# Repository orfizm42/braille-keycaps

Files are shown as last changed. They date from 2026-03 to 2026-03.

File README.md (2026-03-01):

# braille-mx-keycaps

MX互換メカニカルキーボード向け、点字付き3Dプリントキーキャップ

---

## 概要

Cherry MX互換スイッチに対応した点字付きキーキャップのSTEPデータです。メカニカルキーボード愛好家・Makerコミュニティ・研究・教育目的での利用を想定しています。

STEPデータはGitHubで無料公開しています。
boothでも配布しています。
https://orfizm.booth.pm/items/8044609

---

## 特徴

- **62キーフルセット** — アルファベット・数字・ファンクション・修飾・ナビゲーションキーに対応
- **JIS T 0921 / UNESCO準拠の点字ドット** — 直径1.5mm・突出高さ0.5mm・セル間隔2.5mm
- **特殊キー識別リブ** — ファンクション・修飾キーなどの上面左端に縦リブ（高さ0.7mm・幅1.5mm）を配置。点字と混同しない形状で通常キーと触覚的に即座に区別できる設計。
- **OPKベース** — Matt3o氏のOPK（Open Programmatic Keycap、Apache 2.0）をベースに改変

---

## 点字パターンについての注意

特殊キー（Ctrl・Alt・Escなど）の点字パターンは、各キー名称の頭文字に対応するUEB（統一英語点字）Grade 1パターンを割り当てた**独自定義**です。国際標準規格による特殊キーの点字表記は存在しないため、実用目的での使用前に点字の専門家・当事者による監修を推奨します。

---

## リポジトリ構成

```
braille-mx-keycaps/
│  └── fullset/          # 生成済みSTEP・STLファイル
└── README.md
```

---

## 印刷について

点字ドットの突出高さが0.5mm・リブが0.7mmと微細なため、**レジン3Dプリンターを推奨**します。FDMプリンターでは精度が不足する可能性があります。推奨レジン・印刷精度については現在検証中のため、試作結果をもとに随時更新します。

---

## 制作方法について

本プロジェクトはCadQueryライブラリとOPKを組み合わせて実装しました。主な技術的課題と解決方法は以下のとおりです。

**点字ドットの曲面追従**  
キーキャップ上面にはスクープ（くぼみ）があるため、バウンディングボックスのzmax（リム最高点）を基準にするとドットが空中に浮いてしまいます。OCCTのレイキャストAPIを用いて各ドット位置の真上から実際の表面Zを取得し、全てのドットを正確に表面から突出させました。

**ドーム形状の数学的導出**  
底面直径1.5mm・突出高さ0.5mmのドームを球でunionする際の球半径Rを `R = (r² + h²) / (2h)` から導出しています（R ≈ 0.8125mm）。これにより球をunionするだけで自動的に正しいドーム形状が得られます。

**特殊キー識別リブ**  
既存の点字キーボード製品は特殊キーをキー自体の横幅を広げて複数セルの略語で表記していますが、本プロジェクトでは1Uサイズを維持したまま、上面左端に縦リブを配置する独自アプローチを採用しました。リブは点字ドット（球）と同原理で、レイキャストで得た表面Zの真上に直方体を配置しています。

**生成時間の最適化**  
`opk.keycap()`はOCCTのboolean演算を複数回実行するため1呼び出しあたり約2分かかります。同じ`(unitX, unitY, angle)`のキーはベースキャップをキャッシュして使い回すことで、フルセット62キーでの`opk.keycap()`呼び出しを50回から8回に削減しました。

---

## ライセンス

本リポジトリのスクリプトおよびSTEPデータは**CC BY-SA 4.0**で公開します。

OPKは Matt3o 氏が Apache License 2.0 で公開しているものを使用しています。  
© Matt3o — https://github.com/cubiq/OPK

---

## 作者

ORFIZM

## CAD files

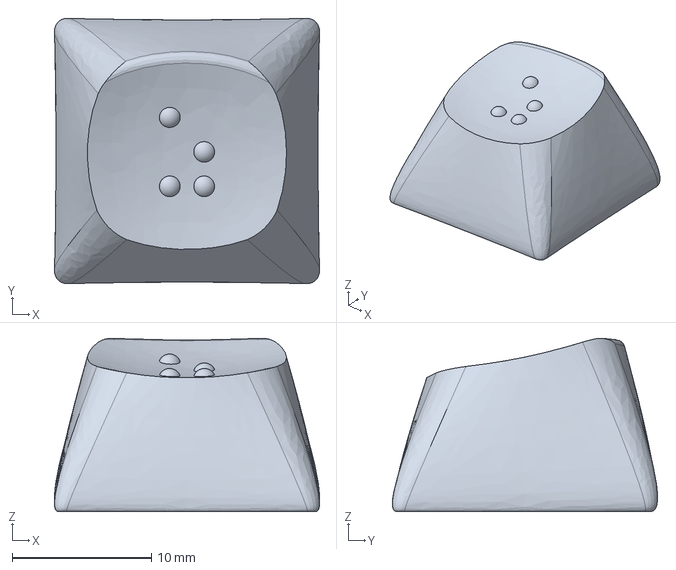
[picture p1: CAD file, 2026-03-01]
alpha/braille_z_1.0u.step
19.0 x 19.0 x 12.4 mm

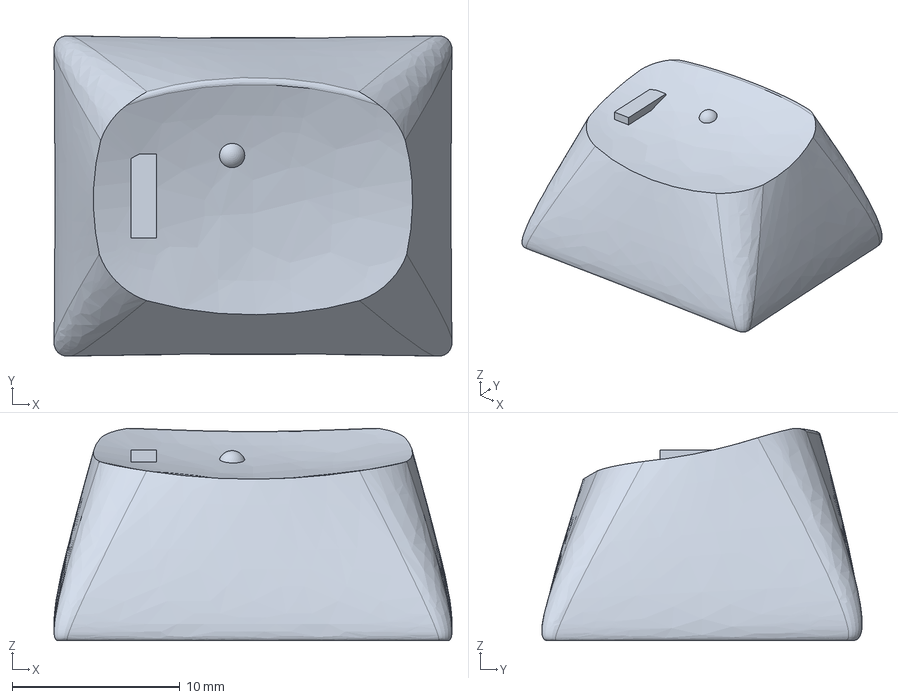
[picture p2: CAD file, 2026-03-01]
special/1.25u/braille_alt_1.25u.step
23.7 x 19.1 x 12.6 mm

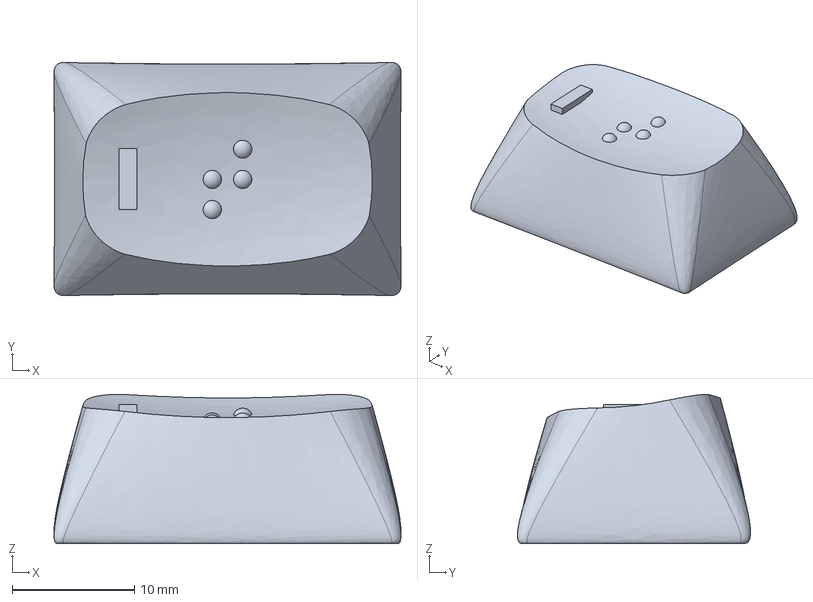
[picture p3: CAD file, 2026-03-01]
special/1.5u/braille_tab_1.5u.step
28.4 x 19.1 x 12.2 mm

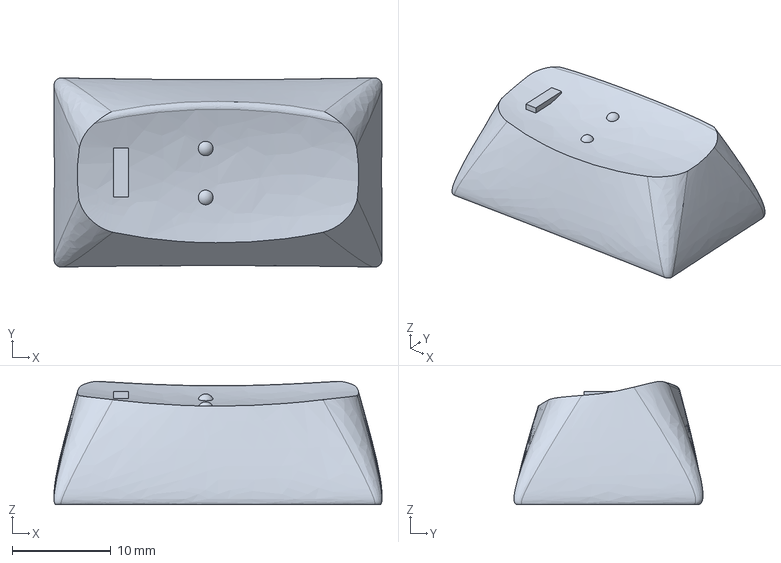
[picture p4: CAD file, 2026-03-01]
special/1.75u/braille_caps_1.75u.step
33.2 x 19.1 x 12.5 mm

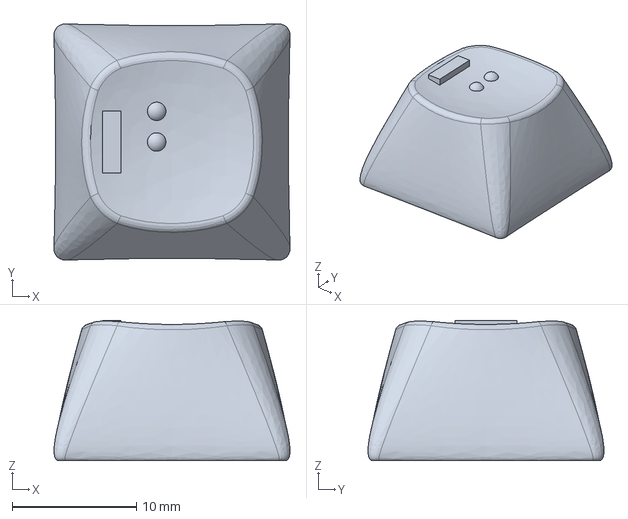
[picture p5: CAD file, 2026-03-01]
special/1u/braille_f2_1.0u.step
19.0 x 19.0 x 11.3 mm

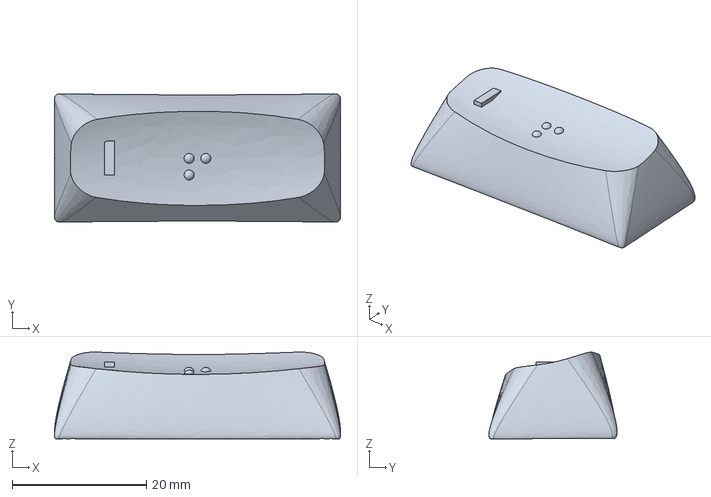
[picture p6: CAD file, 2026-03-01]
special/2.25u/braille_shift_2.25u.step
42.7 x 19.1 x 13.0 mm

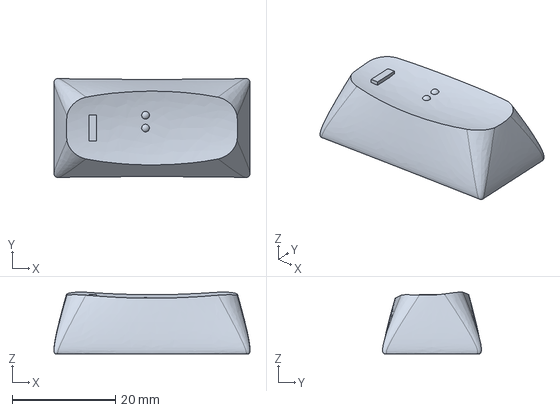
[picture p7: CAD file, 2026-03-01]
special/2u/braille_backspace_2.0u.step
37.9 x 19.1 x 12.0 mm

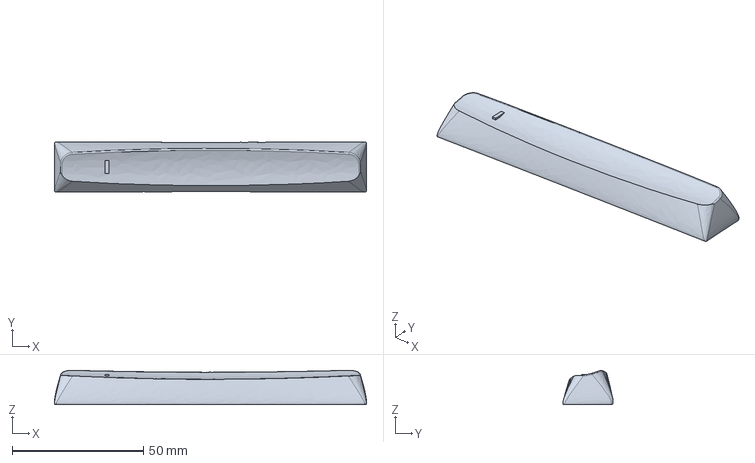
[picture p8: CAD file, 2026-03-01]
special/6.25u/braille_space_6.25u.step
118.8 x 19.2 x 13.1 mm

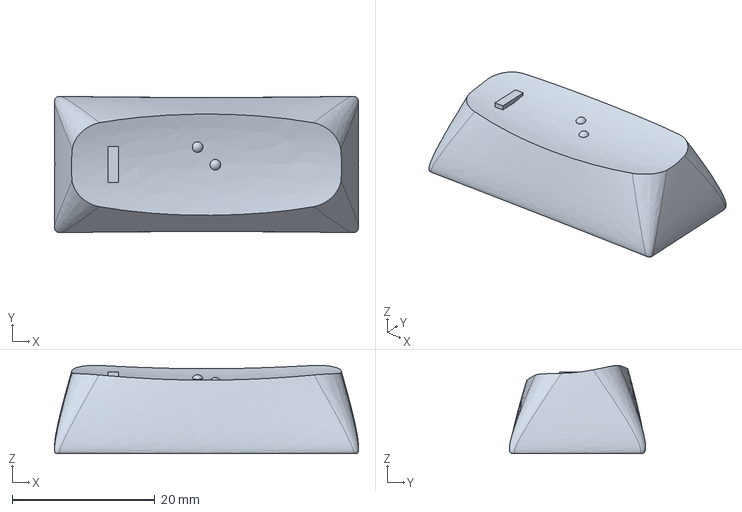
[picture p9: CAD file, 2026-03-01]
special/2.25u/braille_enter_2.25u.step
42.7 x 19.1 x 12.4 mm

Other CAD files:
number/braille_7_1.0u.step
alpha/braille_i_1.0u.step
number/braille_8_1.0u.step
special/1.25u/braille_ctrl_1.25u.step
special/1u/braille_up_1.0u.step
alpha/braille_e_1.0u.step
number/braille_4_1.0u.step
special/1.25u/braille_fn_1.25u.step
special/1u/braille_f4_1.0u.step
alpha/braille_a_1.0u.step
alpha/braille_b_1.0u.step
alpha/braille_c_1.0u.step
alpha/braille_d_1.0u.step
alpha/braille_f_1.0u.step
alpha/braille_g_1.0u.step
alpha/braille_h_1.0u.step
alpha/braille_j_1.0u.step
alpha/braille_k_1.0u.step
alpha/braille_l_1.0u.step
alpha/braille_m_1.0u.step
alpha/braille_n_1.0u.step
alpha/braille_o_1.0u.step
alpha/braille_p_1.0u.step
alpha/braille_q_1.0u.step
alpha/braille_r_1.0u.step
alpha/braille_s_1.0u.step
alpha/braille_t_1.0u.step
alpha/braille_u_1.0u.step
alpha/braille_v_1.0u.step
alpha/braille_w_1.0u.step
alpha/braille_x_1.0u.step
alpha/braille_y_1.0u.step
number/braille_0_1.0u.step
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

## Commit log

2026-03-01 Add QWERTY braille keycap STEP files (62 keys)
    Generated with OPK + CadQuery. Each keycap has:
    - Braille dots (1.5mm diameter, 0.5mm height) on the top surface
    - Vertical rib on the left edge of special keys (1.5x5mm, 0.7mm height)
    Layout:
    - alpha/ : a-z (1U)
    - number/ : 0-9 (1U)
    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
    [braille_0_1.0u.step, braille_1_1.0u.step, braille_2_1.0u.step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]
2026-03-01 README.md の更新
